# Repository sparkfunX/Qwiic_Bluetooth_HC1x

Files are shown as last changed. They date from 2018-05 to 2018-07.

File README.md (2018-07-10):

SparkFun Qwiic Bluetooth
========================================

SparkFun Qwiic Bluetooth (https://www.sparkfun.com/products/14840)

[*SparkX Qwiic Bluetooth (SPX-14840)*](https://www.sparkfun.com/products/14840)

Bluetooth is a great addition to a variety of projects, but the interface to most Bluetooth modules is through a serial UART, which can be a real bummer -- serial port availability can be limited and they're not always super-reliable. The Qwiic Bluetooth aims resolve that issue by providing an I<sup>2</sup>C interface to the HM-13 Bluetooth module.

This board's HM-13 Bluetooth module supports both SPP (Serial Port Profile) and BLE (Bluetooth low-energy) Bluetooth profiles via Bluetooth 4.0. The HM-13's support for BLE means it's compatible with any smartphone.  Or you can connect it to a computer via the old standard -- SPP -- and use it as a transparent Bluetooth data gateway. You can even use it in dual-mode, connected to a pair of devices simultaneously!

The board also features an ATTiny85, which has custom firmware to translate between between I<sup>2</sup>C and serial. There are a pair of Qwiic connectors, which allow you to string a variety of sensors up to a single I<sup>2</sup>C bus. Finally, a green "CON" LED indicates connection status -- blinking when disconnected and solid when connected.

Check out our [HM-13 Arduino library](https://github.com/sparkfun/SparkFun_HM1X_Bluetooth_Arduino_Library) for help developing Bluetooth app of your own! There are a handful of "Qwiic" examples, which demonstrate how to set up a simple serial passthrough, adjust some of the module settings, and even set it up as an **iBeacon**.

SparkFun labored with love to create this code. Feel like supporting open source hardware? 
Buy a [breakout board](https://www.sparkfun.com/products/14840) from SparkFun!

Repository Contents
-------------------

* **/Documents** - Datasheets
* **/Firmware** - I<sup>2</sup>C-to-Serial firmware for ATTiny85 (Arduino code)
* **/Hardware** - Eagle design files (.brd, .sch)

License Information
-------------------

This product is _**open source**_! 

If you have any questions or concerns on licensing, please contact techsupport@sparkfun.com.

Please use, reuse, and modify these files as you see fit. Please maintain attribution to SparkFun Electronics and release any derivative under the same license.

Distributed as-is; no warranty is given.

- Your friends at SparkFun.

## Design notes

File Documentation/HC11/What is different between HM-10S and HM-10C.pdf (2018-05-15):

What’s different between HM-10S and HM-10C?

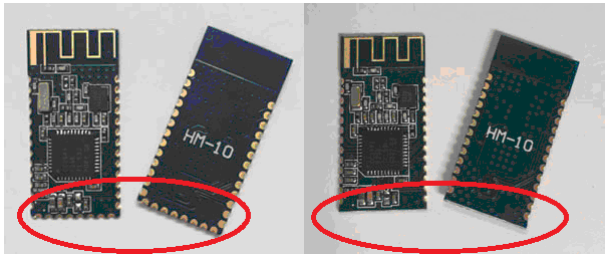
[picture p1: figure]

Left is HM-10S, It have 34 Pads. Right is HM-10C and it only have 26 Pads HM-10C is equal HM-10S removed bottom Pads.

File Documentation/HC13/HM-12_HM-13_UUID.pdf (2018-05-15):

www.jnhuamao.cn

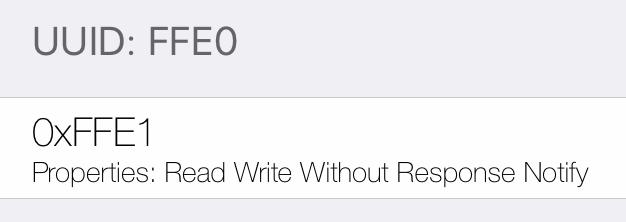
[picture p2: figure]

http://www.jnhuamao.cn

### How to Config HM-12、HM-13 UUID

一、 HM-12、HM-13 Default UUID value

Service UUID

0xFFE0

Characteristic 1 UUID

0xFFE1 （Read，Notify, Write_Without_Response）

二、 If you want to use two Characteristic UUID

Please use AT+FFE21 command to open it, After reset module,

module will use two Characteristic UUID

Service UUID

0xFFE0

Characteristic 1 UUID

0xFFE1 (Read，Notify,)

0xFFE2 (Write_Without_Response)

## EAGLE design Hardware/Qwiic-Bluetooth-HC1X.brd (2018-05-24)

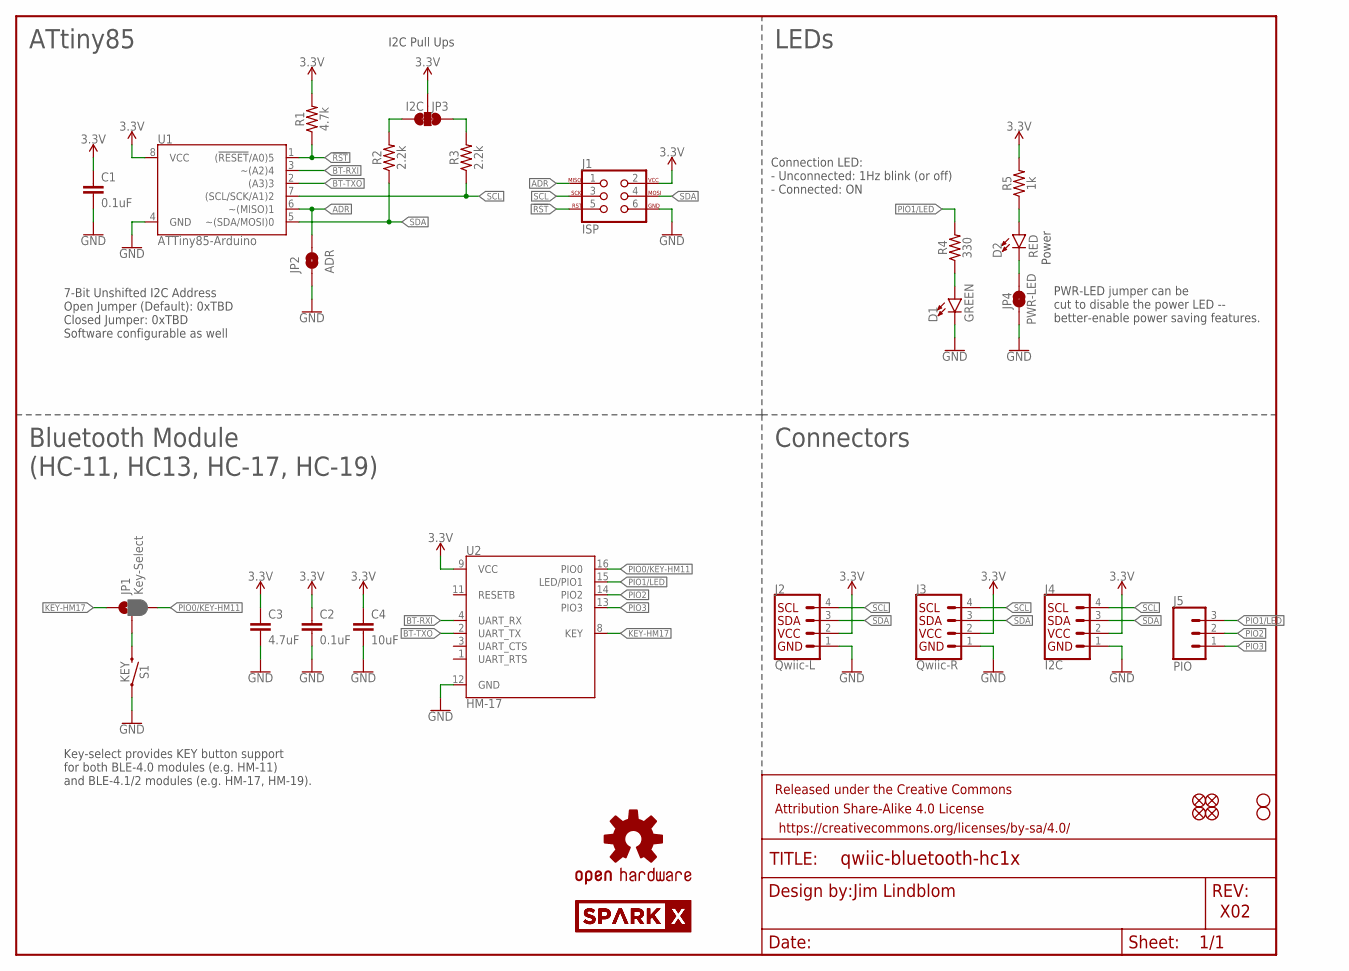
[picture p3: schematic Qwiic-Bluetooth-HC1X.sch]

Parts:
C1, C2: 0.1uF; 0603
C3: 4.7uF; 0603
C4: 10uF; 0603
D1: GREEN; LED-0603
D2: RED; LED-0603
FRAME1: FRAME-LETTER; CREATIVE_COMMONS
J1: ISP; 2X3_TEST_POINTS
J2: Qwiic-L; 1X04_1MM_RA
J3: Qwiic-R; 1X04_1MM_RA
J4: I2C; 1X04_NO_SILK
J5: PIO; 1X03_NO_SILK
JP1: Key-Select; SMT-JUMPER_3_1-NC_PASTE_NO-SILK
JP2: ADR; SMT-JUMPER_2_NO_NO-SILK
JP3: I2C; SMT-JUMPER_3_2-NC_TRACE_NO-SILK
JP4: PWR-LED; SMT-JUMPER_2_NC_TRACE_NO-SILK
JP5, JP6, JP7, JP8: FIDUCIALUFIDUCIAL; FIDUCIAL-MICRO
JP11, JP12: STAND-OFF
LOGO1: OSHW-LOGOMINI; OSHW-LOGO-MINI
LOGO2, LOGO3: SPARKX-LOGO4; SPARKX-MEDIUM
R1: 4.7k; 0603
R2, R3: 2.2k; 0603
R4: 330; 0603
R5: 1k; 0603
S1: KEY; TACTILE_SWITCH_SMD_4.6X2.8MM
U1: ATTiny85-Arduino; SO08-EIAJ_MCU
U2: HM-17; HM-11

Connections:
3.3V: C1.1, C2.1, C3.1, C4.1, J1.2, J2.2, J3.2, J4.2 (VCC), JP3.2, R1.2, R5.2, U1.8 (VCC), U2.9 (VCC)
!RST: J1.5, R1.1, U1.1 ((!RESET!/A0)5)
ADR: J1.1, JP2.2, U1.6 (~(MISO)1)
BT-RXI: U1.3 (~(A2)4), U2.4 (UART_RX)
BT-TXO: U1.2 ((A3)3), U2.2 (UART_TX)
GND: C1.2, C2.2, C3.2, C4.2, D1.C, J1.6, J2.1, J3.1, J4.1 (GND), JP2.1, JP4.1, S1.1, S1.2 (1), U1.4 (GND), U2.12 (GND)
KEY-HM17: JP1.1, U2.8 (KEY)
unnamed: D2.C, JP4.2
unnamed: D1.A, R4.1
unnamed: D2.A, R5.1
unnamed: JP1.2, S1.3 (2), S1.4 (2)
PIO0/KEY-HM11: JP1.3, U2.16 (PIO0)
PIO1/LED: J5.3, R4.2, U2.15 (LED/PIO1)
PIO2: J5.2, U2.14 (PIO2)
PIO3: J5.1, U2.13 (PIO3)
SCL: J1.3, J2.4, J3.4, J4.4 (SCL), R3.1, U1.7 ((SCL/SCK/A1)2)
SCL_PU1: JP3.1, R3.2
SDA: J1.4, J2.3, J3.3, J4.3 (SDA), R2.1, U1.5 (~(SDA/MOSI)0)
SDA_PU1: JP3.3, R2.2

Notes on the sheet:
7-Bit Unshifted I2C Address Open Jumper (Default): 0xTBD Closed Jumper: 0xTBD Software configurable as well
I2C Pull Ups
ATtiny85
Jim Lindblom
X02
Power
Key-select provides KEY button support for both BLE-4.0 modules (e.g. HM-11) and BLE-4.1/2 modules (e.g. HM-17, HM-19).
PWR-LED jumper can be cut to disable the power LED -- better-enable power saving features.
Bluetooth Module (HC-11, HC13, HC-17, HC-19)
LEDs
Connectors
Connection LED: - Unconnected: 1Hz blink (or off) - Connected: ON

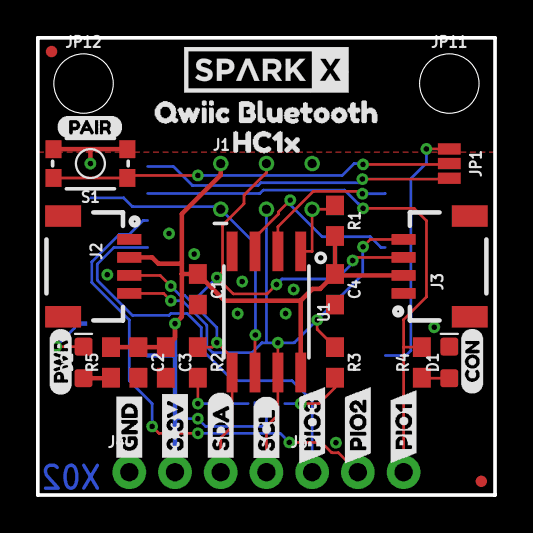
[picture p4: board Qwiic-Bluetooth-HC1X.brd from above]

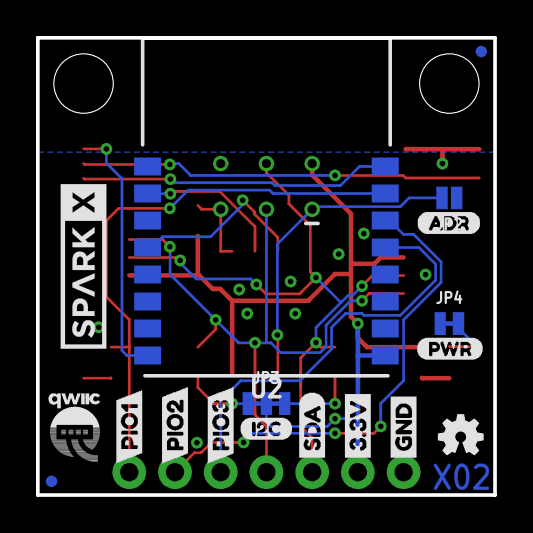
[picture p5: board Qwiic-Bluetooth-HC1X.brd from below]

Board: 2 copper layers, 25.4 x 25.4 mm, 55 parts (18 on the bottom side), 19 nets.

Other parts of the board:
U$1, U$6: SDA4
U$2: HC1X12
U$3, U$22: PIO110
U$4, U$10: GND0
U$5, U$11: 3#3V1
U$7: SCL2
U$8, U$14: PIO33
U$9, U$15: PIO29
U$13, U$16: PWR5
U$17: CON13
U$18: QWIIC_BLUETOOTH11
U$19: ADR8
U$20: I2C7
U$21: QWIIC-LOGO-SMALL
U$23: PAIR15

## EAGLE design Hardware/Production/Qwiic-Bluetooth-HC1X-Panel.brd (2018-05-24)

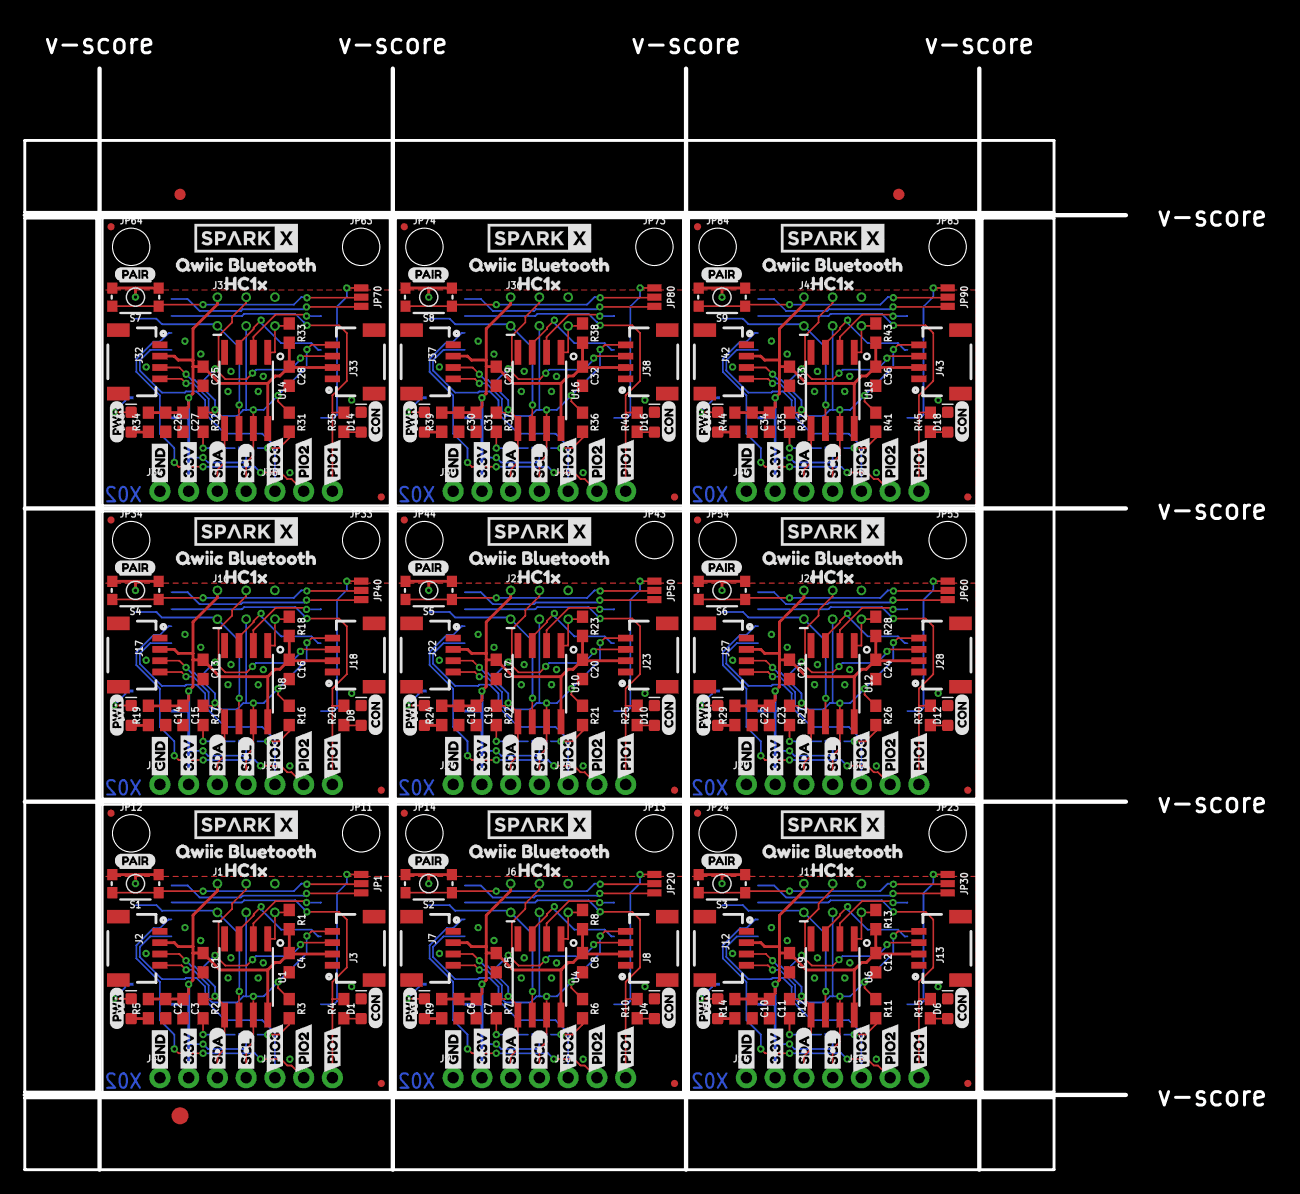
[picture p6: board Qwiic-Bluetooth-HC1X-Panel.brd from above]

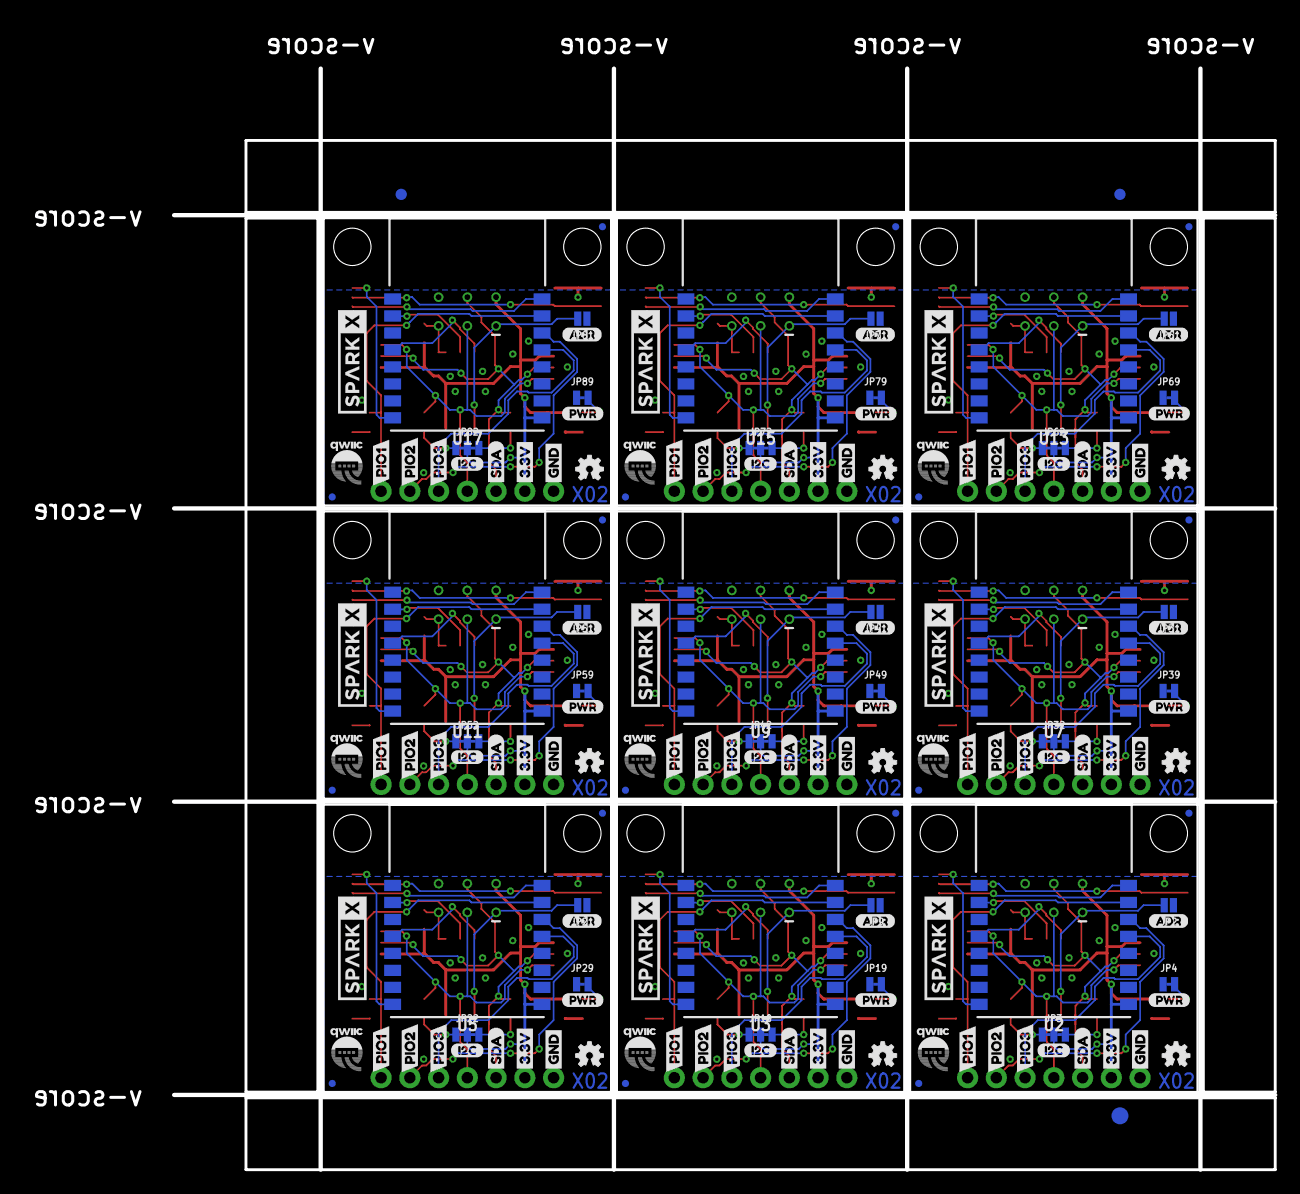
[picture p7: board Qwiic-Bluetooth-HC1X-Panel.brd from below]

Board: 2 copper layers, 97.3 x 97.3 mm, 492 parts (165 on the bottom side), 171 nets.

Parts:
C1, C2, C5, C6, C9, C10, C13, C14, C17, C18, C21, C22, C25, C26, C29, C30, C33, C34: 0.1uF; 0603
C3, C7, C11, C15, C19, C23, C27, C31, C35: 4.7uF; 0603
C4, C8, C12, C16, C20, C24, C28, C32, C36: 10uF; 0603
D1, D4, D6, D8, D10, D12, D14, D16, D18: GREEN; LED-0603
D2, D3, D5, D7, D9, D11, D13, D15, D17: RED; LED-0603
E$1, E$2, E$3, E$4: FIDUCIAL-1X2
E$5, E$6: FIDUCIAL-1.5X3
J1, J6, J11, J16, J21, J26, J31, J36, J41: ISP; 2X3_TEST_POINTS
J2, J7, J12, J17, J22, J27, J32, J37, J42: Qwiic-L; 1X04_1MM_RA
J3, J8, J13, J18, J23, J28, J33, J38, J43: Qwiic-R; 1X04_1MM_RA
J4, J9, J14, J19, J24, J29, J34, J39, J44: I2C; 1X04_NO_SILK
J5, J10, J15, J20, J25, J30, J35, J40, J45: PIO; 1X03_NO_SILK
JP1, JP20, JP30, JP40, JP50, JP60, JP70, JP80, JP90: Key-Select; SMT-JUMPER_3_1-NC_PASTE_NO-SILK
JP2, JP9, JP21, JP31, JP41, JP51, JP61, JP71, JP81: ADR; SMT-JUMPER_2_NO_NO-SILK
JP3, JP10, JP22, JP32, JP42, JP52, JP62, JP72, JP82: I2C; SMT-JUMPER_3_2-NC_TRACE_NO-SILK
JP4, JP19, JP29, JP39, JP49, JP59, JP69, JP79, JP89: PWR-LED; SMT-JUMPER_2_NC_TRACE_NO-SILK
JP5, JP6, JP7, JP8, JP15, JP16, JP17, JP18, JP25, JP26, JP27, JP28, JP35, JP36, JP37, JP38, JP45, JP46, JP47, JP48, JP55, JP56, JP57, JP58, JP65, JP66, JP67, JP68, JP75, JP76, JP77, JP78, JP85, JP86, JP87, JP88: FIDUCIALUFIDUCIAL; FIDUCIAL-MICRO
JP11, JP12, JP13, JP14, JP23, JP24, JP33, JP34, JP43, JP44, JP53, JP54, JP63, JP64, JP73, JP74, JP83, JP84: STAND-OFF
LOGO1, LOGO5, LOGO8, LOGO11, LOGO14, LOGO17, LOGO20, LOGO23, LOGO26: OSHW-LOGOMINI; OSHW-LOGO-MINI
LOGO2, LOGO3, LOGO4, LOGO6, LOGO7, LOGO9, LOGO10, LOGO12, LOGO13, LOGO15, LOGO16, LOGO18, LOGO19, LOGO21, LOGO22, LOGO24, LOGO25, LOGO27: SPARKX-LOGO4; SPARKX-MEDIUM
R1, R8, R13, R18, R23, R28, R33, R38, R43: 4.7k; 0603
R2, R3, R6, R7, R11, R12, R16, R17, R21, R22, R26, R27, R31, R32, R36, R37, R41, R42: 2.2k; 0603
R4, R10, R15, R20, R25, R30, R35, R40, R45: 330; 0603
R5, R9, R14, R19, R24, R29, R34, R39, R44: 1k; 0603
S1, S2, S3, S4, S5, S6, S7, S8, S9: KEY; TACTILE_SWITCH_SMD_4.6X2.8MM
U1, U4, U6, U8, U10, U12, U14, U16, U18: ATTiny85-Arduino; SO08-EIAJ_MCU
U2, U3, U5, U7, U9, U11, U13, U15, U17: HM-17; HM-11
U$1, U$6, U$25, U$40, U$47, U$62, U$69, U$84, U$91, U$106, U$113, U$128, U$135, U$150, U$157, U$172, U$179, U$194: SDA4
U$2, U$43, U$65, U$87, U$109, U$131, U$153, U$175, U$197: HC1X12
U$3, U$22, U$41, U$42, U$63, U$64, U$85, U$86, U$107, U$108, U$129, U$130, U$151, U$152, U$173, U$174, U$195, U$196: PIO110
U$4, U$10, U$12, U$29, U$45, U$51, U$67, U$73, U$89, U$95, U$111, U$117, U$133, U$139, U$155, U$161, U$177, U$183: GND0
U$5, U$11, U$24, U$30, U$46, U$52, U$68, U$74, U$90, U$96, U$112, U$118, U$134, U$140, U$156, U$162, U$178, U$184: 3#3V1
U$7, U$26, U$48, U$70, U$92, U$114, U$136, U$158, U$180: SCL2
U$8, U$14, U$27, U$31, U$49, U$53, U$71, U$75, U$93, U$97, U$115, U$119, U$137, U$141, U$159, U$163, U$181, U$185: PIO33
U$9, U$15, U$28, U$32, U$50, U$54, U$72, U$76, U$94, U$98, U$116, U$120, U$138, U$142, U$160, U$164, U$182, U$186: PIO29
U$13, U$16, U$33, U$38, U$55, U$60, U$77, U$82, U$99, U$104, U$121, U$126, U$143, U$148, U$165, U$170, U$187, U$192: PWR5
U$17, U$34, U$56, U$78, U$100, U$122, U$144, U$166, U$188: CON13
U$18, U$35, U$57, U$79, U$101, U$123, U$145, U$167, U$189: QWIIC_BLUETOOTH11
U$19, U$36, U$58, U$80, U$102, U$124, U$146, U$168, U$190: ADR8
U$20, U$37, U$59, U$81, U$103, U$125, U$147, U$169, U$191: I2C7
U$21, U$39, U$61, U$83, U$105, U$127, U$149, U$171, U$193: QWIIC-LOGO-SMALL
U$23, U$44, U$66, U$88, U$110, U$132, U$154, U$176, U$198: PAIR15

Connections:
3.3V: C1.1, C2.1, C3.1, C4.1, J1.2, J2.2, J3.2, J4.2, JP3.2, R1.2, R5.2, U1.8, U2.9
3.3V1: C5.1, C6.1, C7.1, C8.1, J6.2, J7.2, J8.2, J9.2, JP10.2, R8.2, R9.2, U3.9, U4.8
3.3V2: C9.1, C10.1, C11.1, C12.1, J11.2, J12.2, J13.2, J14.2, JP22.2, R13.2, R14.2, U5.9, U6.8
3.3V3: C13.1, C14.1, C15.1, C16.1, J16.2, J17.2, J18.2, J19.2, JP32.2, R18.2, R19.2, U7.9, U8.8
3.3V4: C17.1, C18.1, C19.1, C20.1, J21.2, J22.2, J23.2, J24.2, JP42.2, R23.2, R24.2, U9.9, U10.8
3.3V5: C21.1, C22.1, C23.1, C24.1, J26.2, J27.2, J28.2, J29.2, JP52.2, R28.2, R29.2, U11.9, U12.8
3.3V6: C25.1, C26.1, C27.1, C28.1, J31.2, J32.2, J33.2, J34.2, JP62.2, R33.2, R34.2, U13.9, U14.8
3.3V7: C29.1, C30.1, C31.1, C32.1, J36.2, J37.2, J38.2, J39.2, JP72.2, R38.2, R39.2, U15.9, U16.8
3.3V8: C33.1, C34.1, C35.1, C36.1, J41.2, J42.2, J43.2, J44.2, JP82.2, R43.2, R44.2, U17.9, U18.8
!RST: J1.5, R1.1, U1.1
!RST1: J6.5, R8.1, U4.1
!RST2: J11.5, R13.1, U6.1
!RST3: J16.5, R18.1, U8.1
!RST4: J21.5, R23.1, U10.1
!RST5: J26.5, R28.1, U12.1
!RST6: J31.5, R33.1, U14.1
!RST7: J36.5, R38.1, U16.1
!RST8: J41.5, R43.1, U18.1
ADR: J1.1, JP2.2, U1.6
ADR1: J6.1, JP9.2, U4.6
ADR2: J11.1, JP21.2, U6.6
ADR3: J16.1, JP31.2, U8.6
ADR4: J21.1, JP41.2, U10.6
ADR5: J26.1, JP51.2, U12.6
ADR6: J31.1, JP61.2, U14.6
ADR7: J36.1, JP71.2, U16.6
ADR8: J41.1, JP81.2, U18.6
BT-RXI: U1.3, U2.4
BT-RXI1: U3.4, U4.3
BT-RXI2: U5.4, U6.3
BT-RXI3: U7.4, U8.3
BT-RXI4: U9.4, U10.3
BT-RXI5: U11.4, U12.3
BT-RXI6: U13.4, U14.3
BT-RXI7: U15.4, U16.3
BT-RXI8: U17.4, U18.3
BT-TXO: U1.2, U2.2
BT-TXO1: U3.2, U4.2
BT-TXO2: U5.2, U6.2
BT-TXO3: U7.2, U8.2
BT-TXO4: U9.2, U10.2
BT-TXO5: U11.2, U12.2
BT-TXO6: U13.2, U14.2
BT-TXO7: U15.2, U16.2
BT-TXO8: U17.2, U18.2
GND: C1.2, C2.2, C3.2, C4.2, D1.C, J1.6, J2.1, J3.1, J4.1, JP2.1, JP4.1, S1.1, S1.2, U1.4, U2.12
GND1: C5.2, C6.2, C7.2, C8.2, D4.C, J6.6, J7.1, J8.1, J9.1, JP9.1, JP19.1, S2.1, S2.2, U3.12, U4.4
GND2: C9.2, C10.2, C11.2, C12.2, D6.C, J11.6, J12.1, J13.1, J14.1, JP21.1, JP29.1, S3.1, S3.2, U5.12, U6.4
GND3: C13.2, C14.2, C15.2, C16.2, D8.C, J16.6, J17.1, J18.1, J19.1, JP31.1, JP39.1, S4.1, S4.2, U7.12, U8.4
GND4: C17.2, C18.2, C19.2, C20.2, D10.C, J21.6, J22.1, J23.1, J24.1, JP41.1, JP49.1, S5.1, S5.2, U9.12, U10.4
GND5: C21.2, C22.2, C23.2, C24.2, D12.C, J26.6, J27.1, J28.1, J29.1, JP51.1, JP59.1, S6.1, S6.2, U11.12, U12.4
GND6: C25.2, C26.2, C27.2, C28.2, D14.C, J31.6, J32.1, J33.1, J34.1, JP61.1, JP69.1, S7.1, S7.2, U13.12, U14.4
GND7: C29.2, C30.2, C31.2, C32.2, D16.C, J36.6, J37.1, J38.1, J39.1, JP71.1, JP79.1, S8.1, S8.2, U15.12, U16.4
GND8: C33.2, C34.2, C35.2, C36.2, D18.C, J41.6, J42.1, J43.1, J44.1, JP81.1, JP89.1, S9.1, S9.2, U17.12, U18.4
KEY-HM1: JP20.1, U3.8
KEY-HM2: JP30.1, U5.8
KEY-HM3: JP40.1, U7.8
KEY-HM4: JP50.1, U9.8
KEY-HM5: JP60.1, U11.8
KEY-HM6: JP70.1, U13.8
KEY-HM7: JP80.1, U15.8
KEY-HM8: JP90.1, U17.8
KEY-HM17: JP1.1, U2.8
unnamed: D2.C, JP4.2
unnamed: D1.A, R4.1
unnamed: D2.A, R5.1
unnamed: JP1.2, S1.3, S1.4
unnamed: D3.A, R9.1
unnamed: D3.C, JP19.2
unnamed: D4.A, R10.1
unnamed: JP20.2, S2.3, S2.4
unnamed: D5.A, R14.1
unnamed: D5.C, JP29.2
unnamed: D6.A, R15.1
unnamed: JP30.2, S3.3, S3.4
unnamed: D7.A, R19.1
unnamed: D7.C, JP39.2
unnamed: D8.A, R20.1
unnamed: JP40.2, S4.3, S4.4
unnamed: D9.A, R24.1
unnamed: D9.C, JP49.2
unnamed: D10.A, R25.1
unnamed: JP50.2, S5.3, S5.4
unnamed: D11.A, R29.1
unnamed: D11.C, JP59.2
unnamed: D12.A, R30.1
unnamed: JP60.2, S6.3, S6.4
unnamed: D13.A, R34.1
unnamed: D13.C, JP69.2
unnamed: D14.A, R35.1
unnamed: JP70.2, S7.3, S7.4
unnamed: D15.A, R39.1
unnamed: D15.C, JP79.2
unnamed: D16.A, R40.1
unnamed: JP80.2, S8.3, S8.4
unnamed: D17.A, R44.1
unnamed: D17.C, JP89.2
unnamed: D18.A, R45.1
unnamed: JP90.2, S9.3, S9.4
PIO0/KEY-HM1: JP20.3, U3.16
PIO0/KEY-HM2: JP30.3, U5.16
PIO0/KEY-HM3: JP40.3, U7.16
PIO0/KEY-HM4: JP50.3, U9.16
PIO0/KEY-HM5: JP60.3, U11.16
PIO0/KEY-HM6: JP70.3, U13.16
PIO0/KEY-HM7: JP80.3, U15.16
PIO0/KEY-HM8: JP90.3, U17.16
PIO0/KEY-HM11: JP1.3, U2.16
PIO1: J10.2, U3.14
PIO1/LED: J5.3, R4.2, U2.15
PIO1/LED1: J10.3, R10.2, U3.15
PIO1/LED2: J15.3, R15.2, U5.15
PIO1/LED3: J20.3, R20.2, U7.15
PIO1/LED4: J25.3, R25.2, U9.15
PIO1/LED5: J30.3, R30.2, U11.15
PIO1/LED6: J35.3, R35.2, U13.15
PIO1/LED7: J40.3, R40.2, U15.15
PIO1/LED8: J45.3, R45.2, U17.15
PIO2: J5.2, U2.14
PIO3: J5.1, U2.13
PIO4: J10.1, U3.13
PIO5: J15.2, U5.14
PIO6: J15.1, U5.13
PIO7: J20.2, U7.14
PIO8: J20.1, U7.13
PIO9: J25.2, U9.14
PIO10: J25.1, U9.13
PIO11: J30.2, U11.14
PIO12: J30.1, U11.13
PIO13: J35.2, U13.14
PIO14: J35.1, U13.13
PIO15: J40.2, U15.14
PIO16: J40.1, U15.13
PIO17: J45.2, U17.14
PIO18: J45.1, U17.13
SCL: J1.3, J2.4, J3.4, J4.4, R3.1, U1.7
SCL1: J6.3, J7.4, J8.4, J9.4, R6.1, U4.7
SCL2: J11.3, J12.4, J13.4, J14.4, R11.1, U6.7
SCL3: J16.3, J17.4, J18.4, J19.4, R16.1, U8.7
SCL4: J21.3, J22.4, J23.4, J24.4, R21.1, U10.7
SCL5: J26.3, J27.4, J28.4, J29.4, R26.1, U12.7
SCL6: J31.3, J32.4, J33.4, J34.4, R31.1, U14.7
SCL7: J36.3, J37.4, J38.4, J39.4, R36.1, U16.7
SCL8: J41.3, J42.4, J43.4, J44.4, R41.1, U18.7
SCL_PU1: JP3.1, R3.2
SCL_PU2: JP10.1, R6.2
SCL_PU3: JP22.1, R11.2
SCL_PU4: JP32.1, R16.2
SCL_PU5: JP42.1, R21.2
SCL_PU6: JP52.1, R26.2
SCL_PU7: JP62.1, R31.2
SCL_PU8: JP72.1, R36.2
SCL_PU9: JP82.1, R41.2
SDA: J1.4, J2.3, J3.3, J4.3, R2.1, U1.5
SDA1: J6.4, J7.3, J8.3, J9.3, R7.1, U4.5
SDA2: J11.4, J12.3, J13.3, J14.3, R12.1, U6.5
SDA3: J16.4, J17.3, J18.3, J19.3, R17.1, U8.5
SDA4: J21.4, J22.3, J23.3, J24.3, R22.1, U10.5
SDA5: J26.4, J27.3, J28.3, J29.3, R27.1, U12.5
SDA6: J31.4, J32.3, J33.3, J34.3, R32.1, U14.5
SDA7: J36.4, J37.3, J38.3, J39.3, R37.1, U16.5
SDA8: J41.4, J42.3, J43.3, J44.3, R42.1, U18.5
SDA_PU1: JP3.3, R2.2
SDA_PU2: JP10.3, R7.2
SDA_PU3: JP22.3, R12.2
SDA_PU4: JP32.3, R17.2
SDA_PU5: JP42.3, R22.2
SDA_PU6: JP52.3, R27.2
SDA_PU7: JP62.3, R32.2
SDA_PU8: JP72.3, R37.2
SDA_PU9: JP82.3, R42.2

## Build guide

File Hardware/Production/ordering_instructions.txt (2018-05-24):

panel size, 91x91mm
PCB thickness, 1.6mm
number of layers, 2
soldermask color, Black
silkscreen color, White
oz copper, 1oz
finish, HASL lead free
stencils, top
pcs per panel, 9

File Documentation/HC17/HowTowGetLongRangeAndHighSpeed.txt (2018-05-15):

1. Let module Antenna out of your board.
2. Use 10uF or 47uF capcacity on module VCC pin.
3. Setup AT+POWE7 get more power.
4. Setup AT+GAIN1 and AT+GAIT1.
5. Use V120 or higher firmware version.
6. Since V120 module send to android device could send 253 Bytes per package.

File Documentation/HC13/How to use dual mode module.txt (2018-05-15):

1. Default baud rate is 115200, N, 8, 1.

2. module contains tow MAC address, 00:0E:0B:xx:xx:xx is BLE mode, 00:0E:0E:xx:xx:xx is EDR mode.

3. Our company provides two version bluetooth serial assistant, BLE Comassistant and SPP ComAssistant.

4. Dont iperate the BLE in android Bluetooth management interface.

5. Before V216 PIO0 must be pull up.

6. Since V216 you can shut down PIO0 function use "AT+PIO0" command. After execute "AT+PIO00" command, you can left PIO0 NC.

7. Since V216 we setup "AT+PIO00" as default settings.

8. Query version command is "AT+VERS?"

9. The AT command is uppercase characters, dont have any other symbols.

A. Dual mode module dont have high speed, Please make some delay time between two packages.

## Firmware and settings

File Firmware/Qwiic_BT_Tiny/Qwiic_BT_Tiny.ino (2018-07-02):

/*
  Qwiic Bluetooth 4.0 - HM-13
  By: Jim Lindblom
  SparkFun Electronics
  Date: July 2, 2018
  License: This code is public domain but you buy me a beer if you use this and we meet someday (Beerware license).

  An ATtiny84 receives I2C commands from a master and sends/receives commands over serial to the
  HM-13 Bluetooth module. Supported commands include:
  
  0x00: Bytes available - Returns number of bytes stored in ATtiny's I2C receive buffer.
    - Maximum value will be 128 bytes (I2C_TX_BUFFER_SIZE).
    - This is data incoming from the HM-13 module.
  0x01: Read serial data - Reads out a requested number of bytes from the I2C receive buffer.
    - This command requires a second byte, written after the command byte -- NUMBER OF BYTES TO READ
    - [0x02] [NUM_BYTES_TO_READ] [BYTE 0] ... [BYTE N]
    - NUMBER OF BYTES TO READ should not exceed 32 bytes.
  0x02: Write serial data - Write data to the serial device.
    - This commaand requires a second byte, written after the command byte -- NUMBER OF BYTES TO WRITE
    - [0x02] [NUM_BYTES_TO_WRITE] [BYTE 0] ... [BYTE N]
    - NUMBER OF BYTES TO WRITE should not exceed 32 bytes
  0x03: Set baud rate - Sets serial port baud rate to the requested value.
    - This command requires a second byte, written after the command byte -- BAUD_RATE_INDEX.
    - BAUD_RATE_INDEX should be one of the following 8-bit values:
      - 1: 4800 bps             - 5: 57600 bps
      - 2: 9600 bps             - 6: 115200 bps
      - 3: 19200 bps            - 7: 230400 bps
      - 4: 38400 bps
  0x04: Set I2C address - Sets device address of this module
    - This command requires a second byte, written after the command byte -- SET_BAUD_ADDRESS
    - SET_BAUD_ADDRESS should be a value between 0x09 and 0x76
*/

#include <SoftwareSerial.h>
#include <Wire.h>
#include <EEPROM.h>
#include "qwiic_bt_tiny_config.h"

SoftwareSerial btSerial(3, 4); // RX, TX on Tiny

#define I2C_ADDRESS_PIN 1 // MISO on the ATTiny85

// These are the I2C commands supported by this firmware
typedef enum {
  // Read number of bytes available in I2C TX buffer
  I2C_BYTES_AVAILABLE, // 0x00
  // Request a number of bytes from the I2C TX buffer
  I2C_READ_RAW_DATA,   // 0x01
  // Write data to the serial RX buffer
  I2C_WRITE_RAW_DATA,  // 0x02
  // Set serial baud rate
  I2C_SET_BAUD,        // 0x03
  // Set I2C address
  I2C_SET_ADDRESS,     // 0x04
  // Factory reset
  I2C_FACTORY_RESET,   // 0x05

  I2C_INVALID
} qwiic_bt_commands_t;

volatile qwiic_bt_commands_t lastCommand = I2C_INVALID;

typedef enum {
  BAUD_INVALID,  // 0
  BAUD_4800,     // 1
  BAUD_9600,     // 2
  BAUD_19200,    // 3
  BAUD_38400,    // 4
  BAUD_57600,    // 5
  BAUD_115200,   // 6
  BAUD_230400,   // 7
  NUM_BAUD_RATES // 8
} bt_baud_rates_t;
const long btBauds[NUM_BAUD_RATES] = {0, 4800, 9600, 19200, 38400, 57600, 115200, 320400};
bt_baud_rates_t oldBaud;
bt_baud_rates_t newBaud;

void setup() {  
  delay(2000); // Delay to allow BT module to initialize
  
  // Set up software serial port -- Begin by attempting to set baud rate from 115200 to 9600
  btSerial.begin(115200);
  btSerial.print("AT"); // Disconnect if connected
  delay(500);
  btSerial.print("AT+BAUD2"); // Force HM-13 module's UART from 115200 (default) to 9600
  delay(500);
  btSerial.print("AT+RESET"); // Restart module -- should only execute if the module is at 115200 baud
  delay(2000); // Wait for reset if "AT+RESET" worked
  
  setBaud(BAUD_9600);
  btSerial.print("AT"); // Disconnect/test connection
  
  initWire();
}

void loop() {
  if (btSerial.available()) {
    writeRingBuffer(btSerial.read());
  }
  if (oldBaud != newBaud) {
    setBaud(newBaud);
  }
}

void factoryReset(void) {
  // TODO: Reset EEPROM values to defaults.
}

void setBaud(bt_baud_rates_t baud) {
  int baudIndex = baud;
  
  if ((baudIndex == BAUD_INVALID) || (baudIndex>= NUM_BAUD_RATES)) {
    // Default to 9600 if baud is incorrectly stored
    baudIndex = BAUD_9600;
  }
  btSerial.begin(btBauds[baudIndex]);
  storeBaudIndex(baudIndex);
  
  oldBaud = baudIndex;
  newBaud = baudIndex;
}

void i2cReceive(int numBytesReceived) {
  byte commandByte;

  if (numBytesReceived < 1) {
    return; // Error
  }

  // First byte should be a command
  commandByte = Wire.read();

  // Return number of bytes available in Serial RX (I2C TX) buffer
  if ((qwiic_bt_commands_t) commandByte == I2C_BYTES_AVAILABLE) {
    lastCommand = commandByte;
  }
  // Read from Serial RX (I2C TX) buffer
  else if (((qwiic_bt_commands_t) commandByte == I2C_READ_RAW_DATA) && (numBytesReceived == 2)) {
    lastCommand = commandByte;
    setI2cBytesToRead(Wire.read());
  }
  // Send data to the Serial TX buffer
  else if (((qwiic_bt_commands_t) commandByte == I2C_WRITE_RAW_DATA) && (numBytesReceived >= 2)) {
    for (int i = 1; i < numBytesReceived; i++) {
      char c = Wire.read();
      btSerial.write(c);
    }
  }
  // Set software serial baud rate
  else if (((qwiic_bt_commands_t) commandByte == I2C_SET_BAUD) && (numBytesReceived == 2)) {
    newBaud = Wire.read(); // Loop will pick up new baud setting and update software serial
  }
  // Set new I2C address
  else if (((qwiic_bt_commands_t) commandByte == I2C_SET_ADDRESS) && (numBytesReceived == 2)) {
    storeI2cAddress(Wire.read());
  }
  else if (((qwiic_bt_commands_t) commandByte == I2C_FACTORY_RESET) && (numBytesReceived == 2)) {
    uint8_t resetCmd = Wire.read();
    if (resetCmd == 1) {
      factoryReset();
    }
  }
  else {
    lastCommand = I2C_INVALID;
  }
}

void i2cRequest(void) {
  switch (lastCommand) {
    case I2C_BYTES_AVAILABLE:
      i2cRequestAvailable();
      break;
    case I2C_READ_RAW_DATA:
      i2cRequestData();
      break;
    default:
      break;
  }
}

void initWire(void) {
  initRingBuffer();
  Wire.end(); // Before we can change address, need to end wire

  pinMode(I2C_ADDRESS_PIN, INPUT_PULLUP);
  // Read the ADR pin -- if it's low set the I2C address to the pre-configured address
  if (digitalRead(I2C_ADDRESS_PIN) == LOW) {
    Wire.begin(I2C_ADDRESS_JUMPED);
  } else {
    // If the ADR jumper is un-set (pulled high internally), use either the default
    // address or the address configured in EEPROM
    //Wire.begin(loadI2cAddress());
    Wire.begin(I2C_ADDRESS_DEFAULT);
  }

  Wire.onReceive(i2cReceive);
  Wire.onRequest(i2cRequest);
}

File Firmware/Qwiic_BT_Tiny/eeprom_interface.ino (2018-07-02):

#include "qwiic_bt_tiny_config.h"

#define EEPROM_ADR_I2C_ADDRESS  0x01 // Stored I2C Address
#define EEPROM_ADR_BAUD         0x02 // Baud rate index (1-7)

uint8_t loadI2cAddress(void) {
  uint8_t storedI2cAddress = EEPROM.read(EEPROM_ADR_I2C_ADDRESS);
  
  if (storedI2cAddress == 255) {
    storedI2cAddress = I2C_ADDRESS_DEFAULT;
    EEPROM.write(EEPROM_ADR_I2C_ADDRESS, storedI2cAddress);
  }
  
  return storedI2cAddress;
}

void storeI2cAddress(uint8_t address) {
  // Ensure the address is within the allowed range
  if ((address < 0x08) || (address > 0x77)) {
    return;
  }
  EEPROM.write(EEPROM_ADR_I2C_ADDRESS, address);
}

uint8_t loadBaudIndex(void) {
  uint8_t storedBaud = EEPROM.read(EEPROM_ADR_BAUD);
  if (storedBaud == 255) {
    storedBaud = BAUD_9600;
    EEPROM.write(EEPROM_ADR_BAUD, storedBaud);
  }
}

void storeBaudIndex(uint8_t baud) {
  uint8_t baudIndex = baud;
  if ((baudIndex== BAUD_INVALID) || (baudIndex>= NUM_BAUD_RATES)) {
    // Default to 9600 if baud is incorrectly stored
    baudIndex = BAUD_9600;
  }
  EEPROM.write(EEPROM_ADR_BAUD, baudIndex);
}

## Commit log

2018-05-15 initial commit of hardware
    [Qwiic-Bluetooth-HC1X.brd, Qwiic-Bluetooth-HC1X.sch]
2018-05-15 Adding decoupling, fixing silk.
    [Qwiic-Bluetooth-HC1X.brd, Qwiic-Bluetooth-HC1X.sch]
2018-05-15 Adding 3x3 panel and gerber.
    [Qwiic-Bluetooth-HC1X-Panel.GBL, Qwiic-Bluetooth-HC1X-Panel.GBO, Qwiic-Bluetooth-HC1X-Panel.GBP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]
2018-05-24 Fixing HM-17 pinout, and revising layout to x02
    [Qwiic-Bluetooth-HC1X.brd, Qwiic-Bluetooth-HC1X.sch]
2018-05-24 Pushing production panel for x02.
    [Qwiic-Bluetooth-HC1X-Panel.brd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]

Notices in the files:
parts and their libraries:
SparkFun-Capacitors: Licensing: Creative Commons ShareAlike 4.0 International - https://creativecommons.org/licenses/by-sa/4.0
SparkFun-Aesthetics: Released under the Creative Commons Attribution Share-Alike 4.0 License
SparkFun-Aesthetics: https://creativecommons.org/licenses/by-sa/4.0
